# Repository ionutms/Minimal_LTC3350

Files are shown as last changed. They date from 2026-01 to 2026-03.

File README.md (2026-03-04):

# Minimal_LTC3350

## Overview

This repository contains a minimal KiCad design project for the Analog Devices LTC3350, a high-current supercapacitor backup controller and system monitor. The project includes schematic designs and PCB layout files for implementing this versatile backup power solution.

## Disclaimer

> [!NOTE]
> This project is provided "as is" and without any warranty, express or implied. For more details, please see the [LICENSE](LICENSE) file.

## About the LTC3350

The LTC3350 from Analog Devices is a high-current supercapacitor backup controller and system monitor designed for high-reliability backup power applications. It integrates a synchronous step-down/step-up controller that charges and monitors a series stack of 1–4 supercapacitors.

Key features include:

- **High-Efficiency Power Conversion:**
  - Synchronous step-down CC/CV charging for 1–4 series supercapacitors
  - Step-up mode in backup for greater utilization of stored energy
  - Supports 10A+ charge and backup currents
- **Advanced Monitoring:**
  - 14-bit ADC for monitoring system voltages and currents
  - Capacitance and ESR monitoring
  - I²C/SMBus interface for reading monitored parameters
- **Protection Features:**
  - Active overvoltage protection shunts
  - Internal active balancers (no external balance resistors needed)
  - Dual ideal diode PowerPath™ controller with N-channel MOSFETs
- **Programmable Current Limit:** Prioritizes system load over capacitor charge current
- **Wide Operating Range:**
  - Input Voltage (VIN): 4.5V to 35V
  - Capacitor Voltage (VCAP): Up to 5V per capacitor
- **Package:** Available in a 38-lead QFN package (5mm × 7mm × 0.75mm) with exposed pad
- **Automotive Qualified:** AEC-Q100 qualified for automotive applications

## Project Structure

```
minimal_ltc3350/
├── minimal_ltc3350.kicad_pro                     # Project configuration file
├── minimal_ltc3350.kicad_sch                     # Main schematic file
├── minimal_ltc3350.kicad_pcb                     # PCB layout file
├── fp-lib-table                                  # Footprint library table
├── sym-lib-table                                 # Symbol library table
├── docs/                                         # Documentation files
│   ├── bom/                                      # Bill of Materials
│   │   └── minimal_ltc3350_ibom.html             # Interactive BOM file
│   ├── pictures/                                 # Images and photos
│   │   ├── 1_minimal_ltc3350_side.png            # Side view of PCB
│   │   ├── 2_minimal_ltc3350_top.png             # Top view of PCB
│   │   └── 3_minimal_ltc3350_bottom.png          # Bottom view of PCB
│   └── schematics/                               # Schematic PDF exports
│       └── minimal_ltc3350_schematics.pdf        # Complete schematics PDF
└── KiCAD_Symbols_Generator/                      # Submodule for symbol generation from CSV data
```

## Project Features

This design provides a minimal implementation of the LTC3350 with:

- Proper power supply connections for 4.5V to 35V input range
- Supercapacitor stack configuration (1–4 series capacitors)
- Active balancing circuitry
- I²C/SMBus communication interface
- Current sensing and monitoring
- Standard footprint for the 38-lead QFN package

## Getting Started

### Prerequisites

- [KiCad EDA](https://www.kicad.org/) version 9.0 or later installed on your system
- Git (for cloning the repository and submodule management)

### Opening the Project

1. **Clone the repository** (including submodules):
   ```bash
   git clone --recursive https://github.com/ionutms/Minimal_LTC3350.git
   ```

   If you've already cloned the repository without submodules, initialize them with:
   ```bash
   git submodule init
   git submodule update
   ```

2. **Open the project in KiCad**:
   - Launch KiCad
   - Click "Open Existing Project"
   - Navigate to the cloned repository folder
   - Select the `minimal_ltc3350.kicad_pro` file

3. **Explore the design**:
   - Open the schematic editor to view the circuit design
   - Open the PCB editor to view the board layout
   - Review the symbol and footprint libraries used in the design

### Project Files

- **Main schematic**: `minimal_ltc3350.kicad_sch` - Contains the primary circuit design with the LTC3350 and support components
- **PCB layout**: `minimal_ltc3350.kicad_pcb` - Physical board design file with proper component placement
- **Project configuration**: `minimal_ltc3350.kicad_pro` - KiCad project settings

## Dependencies

This project has the following dependencies:

### 1. KiCAD Symbols Generator

This repository uses [KiCAD_Symbols_Generator](https://github.com/ionutms/KiCAD_Symbols_Generator) as a submodule for custom symbol generation.

To initialize the submodule after cloning this repository:

```bash
git submodule update --init --recursive
```

### 2. 3D Models

This project requires the [3D_Models_Vault](https://github.com/ionutms/3D_Models_Vault) repository for 3D models.

#### Setup for KiCAD 9:

1. Clone the 3D models repository:
   ```bash
   git clone https://github.com/ionutms/3D_Models_Vault.git
   ```

2. In KiCAD 9, add an environment variable:
   - Variable name: `KICAD9_3D_MODELS_VAULT`
   - Variable value: Full path to where you cloned the 3D_Models_Vault repository

## Usage

After setting up the dependencies, open the project in KiCad 9 to access all features including the 3D models.

## Symbol Generator Submodule

This project includes the KiCAD_Symbols_Generator as a submodule, which provides tools for generating KiCad symbols from CSV data files. For more information on using this tool, see the [KiCAD_Symbols_Generator documentation](minimal_ltc3350/KiCAD_Symbols_Generator/README.md).

## Documentation

The `docs` folder contains:
- Schematic PDF exports
- Images and photos of the design

## Visuals

The following images showcase the PCB design from different perspectives:

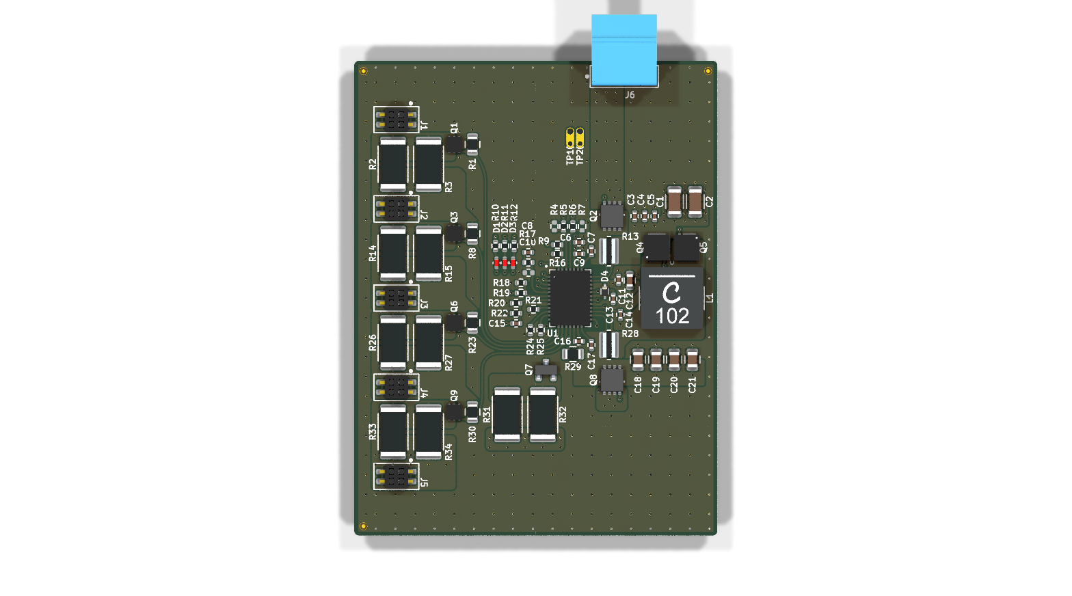
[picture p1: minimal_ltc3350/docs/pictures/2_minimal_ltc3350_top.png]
Top View

*Top View of the PCB*

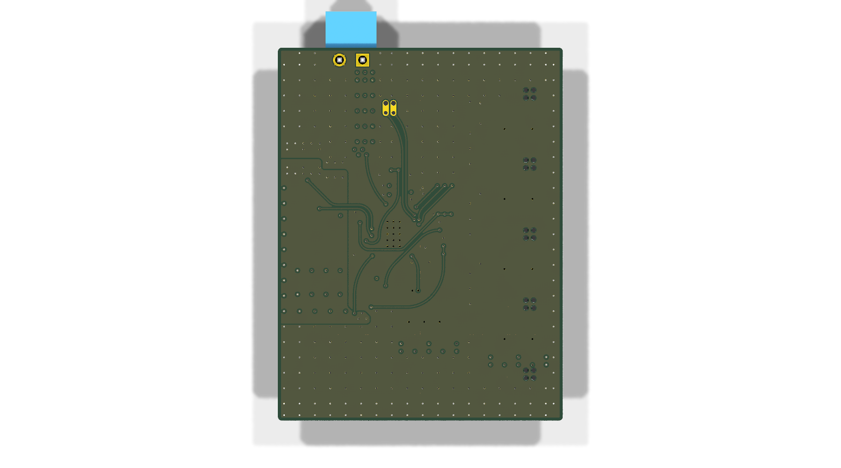
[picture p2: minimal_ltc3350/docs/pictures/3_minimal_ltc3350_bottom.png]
Bottom View

*Bottom View of the PCB*

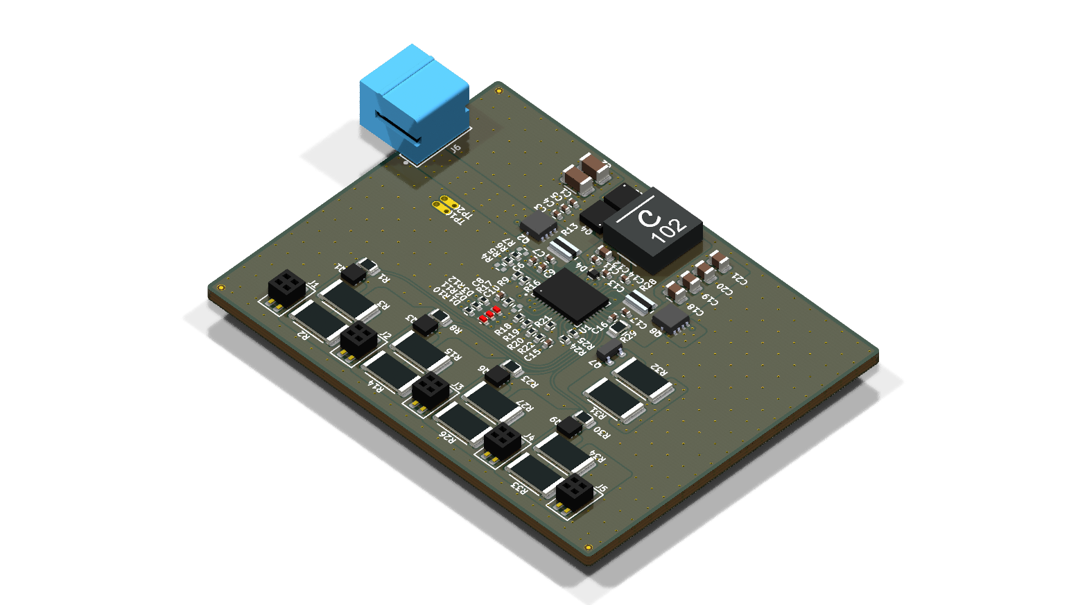
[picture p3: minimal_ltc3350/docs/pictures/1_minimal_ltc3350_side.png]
Side View

*Side View of the PCB*

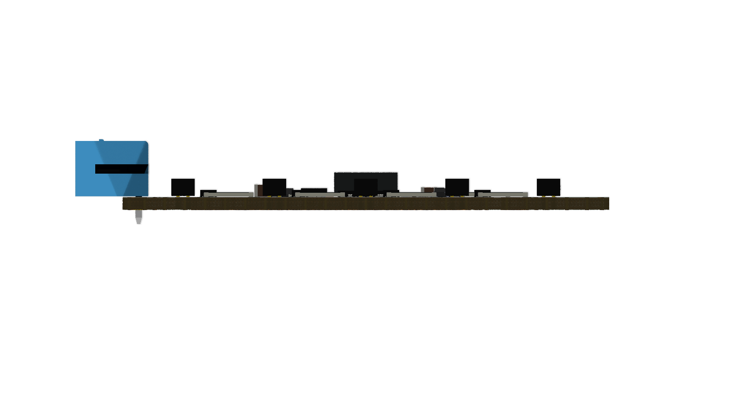
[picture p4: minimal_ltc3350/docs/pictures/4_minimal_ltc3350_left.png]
Left View

*Left View of the PCB*

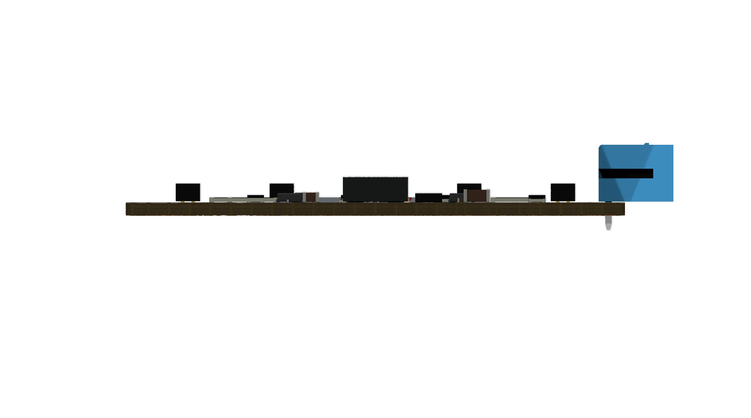
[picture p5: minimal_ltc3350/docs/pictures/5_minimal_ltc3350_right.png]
Right View

*Right View of the PCB*

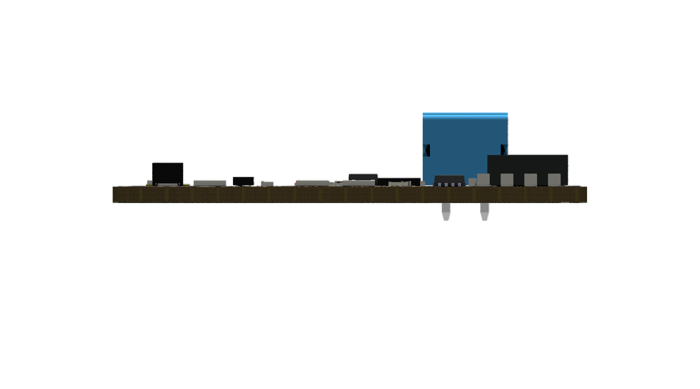
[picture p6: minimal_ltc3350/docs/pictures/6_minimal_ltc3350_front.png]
Front View

*Front View of the PCB*

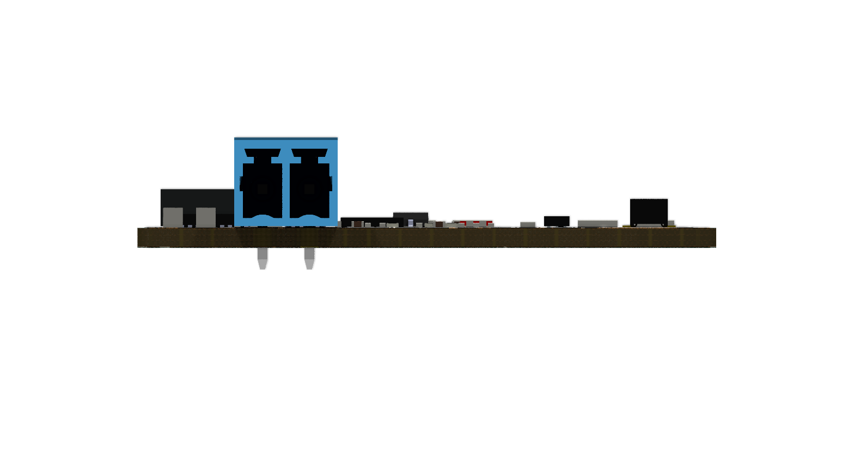
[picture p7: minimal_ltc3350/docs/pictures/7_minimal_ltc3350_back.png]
Back View

*Back View of the PCB*

## License

This project is licensed under the MIT License - see the [LICENSE](LICENSE) file for details.

## References

- [LTC3350 Datasheet](https://www.analog.com/media/en/technical-documentation/data-sheets/ltc3350.pdf)
- [LTC3350 Product Page](https://www.analog.com/en/products/ltc3350.html)
- [KiCad EDA](https://www.kicad.org/)

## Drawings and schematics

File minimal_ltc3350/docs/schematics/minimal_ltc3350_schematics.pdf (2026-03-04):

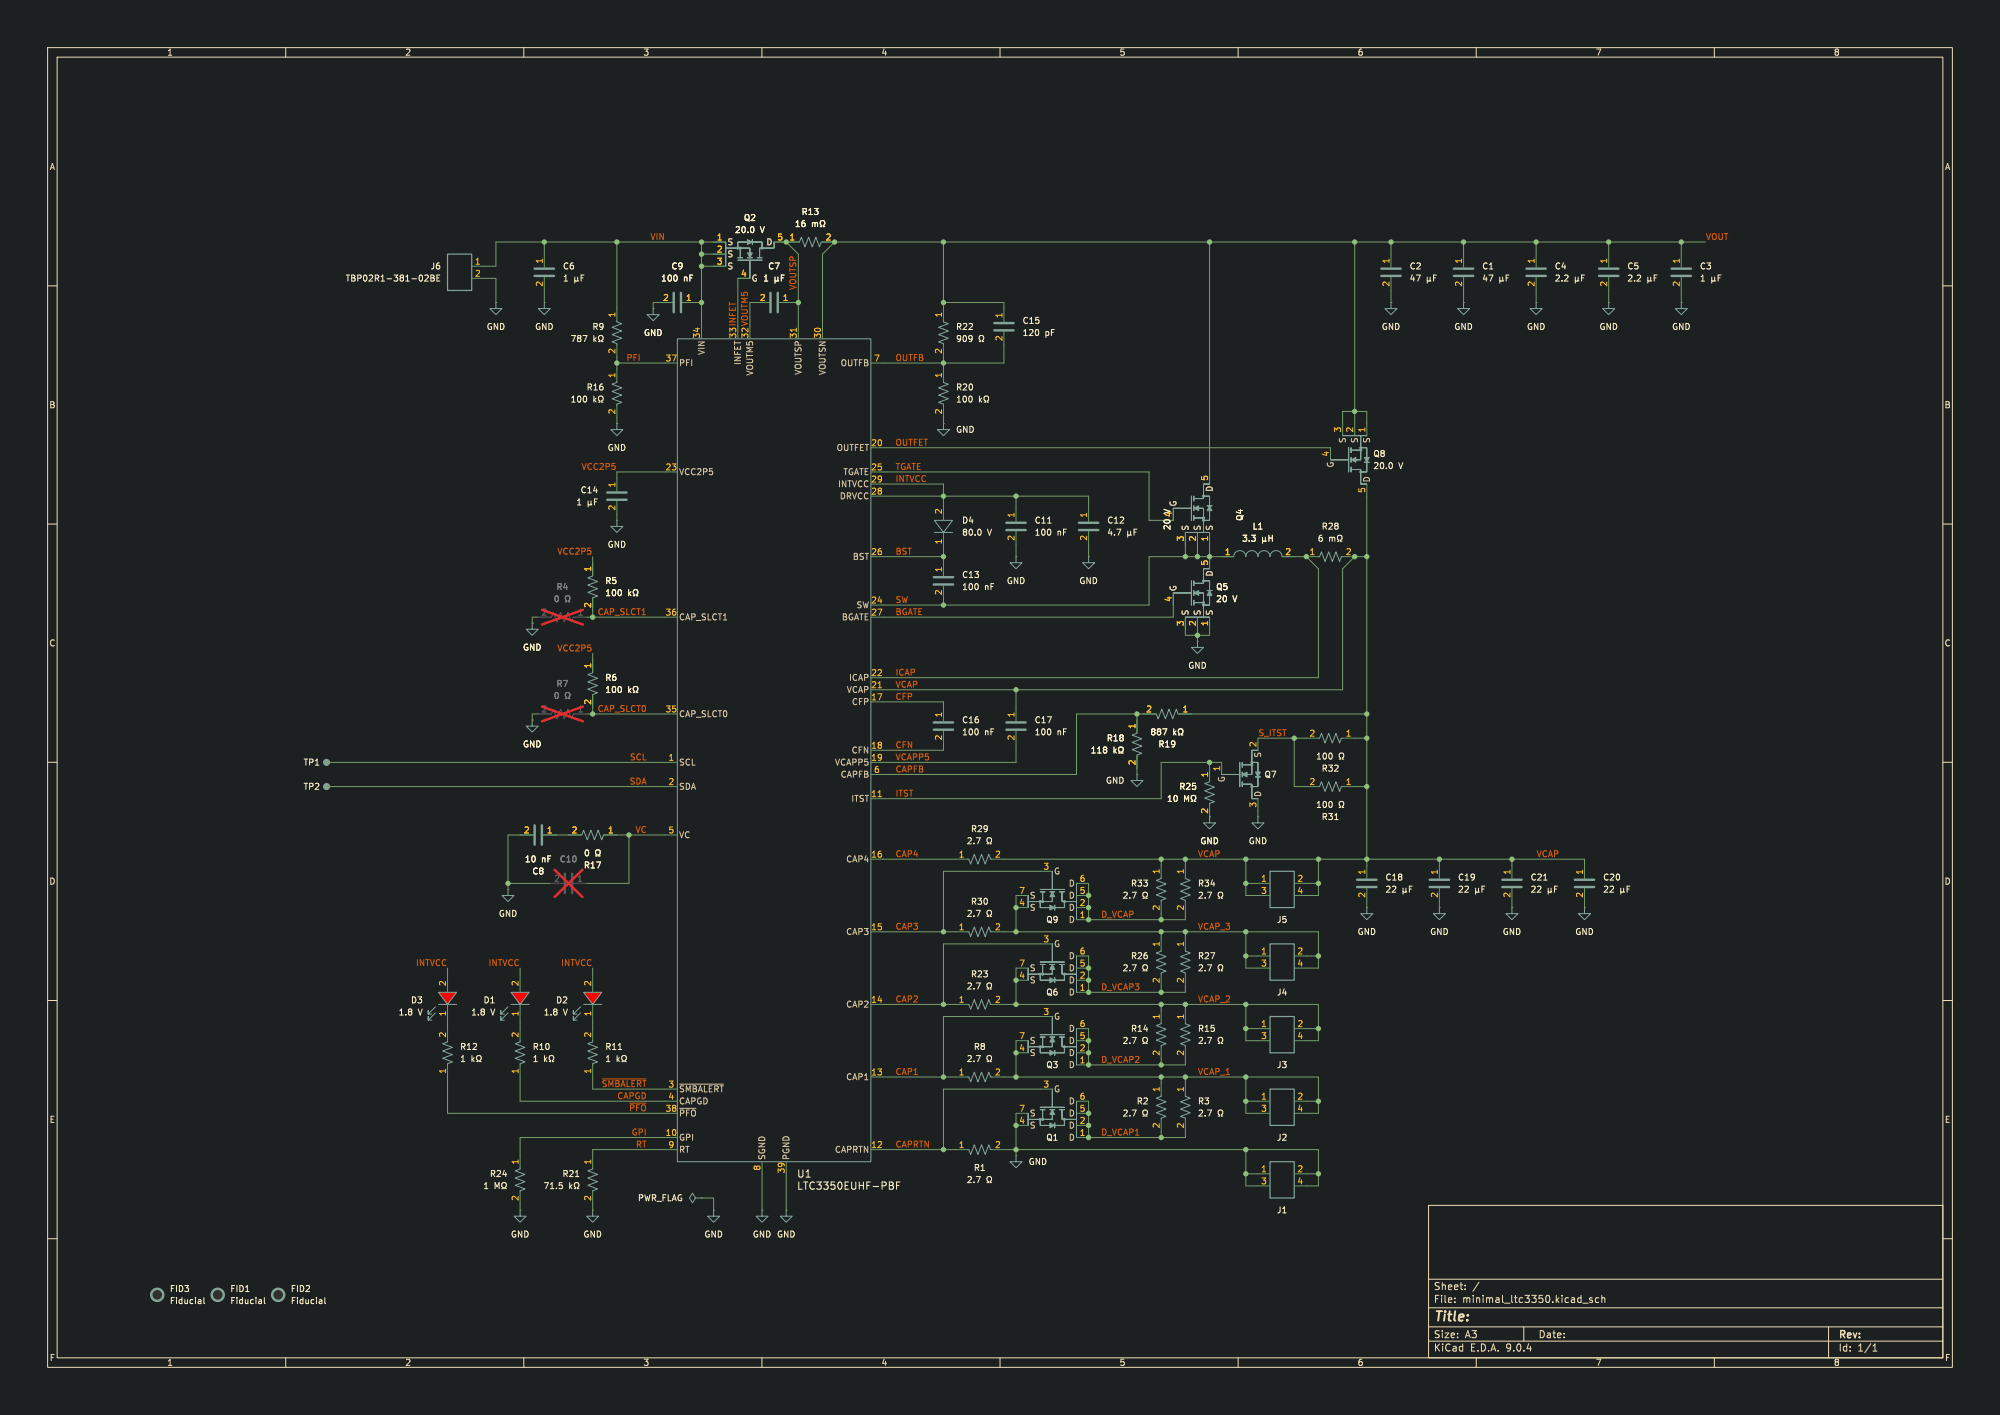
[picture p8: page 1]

8 PGND 39 VOUTSP 31 VOUTSN 30 OUTFB 7 OUTFET20 TGATE25

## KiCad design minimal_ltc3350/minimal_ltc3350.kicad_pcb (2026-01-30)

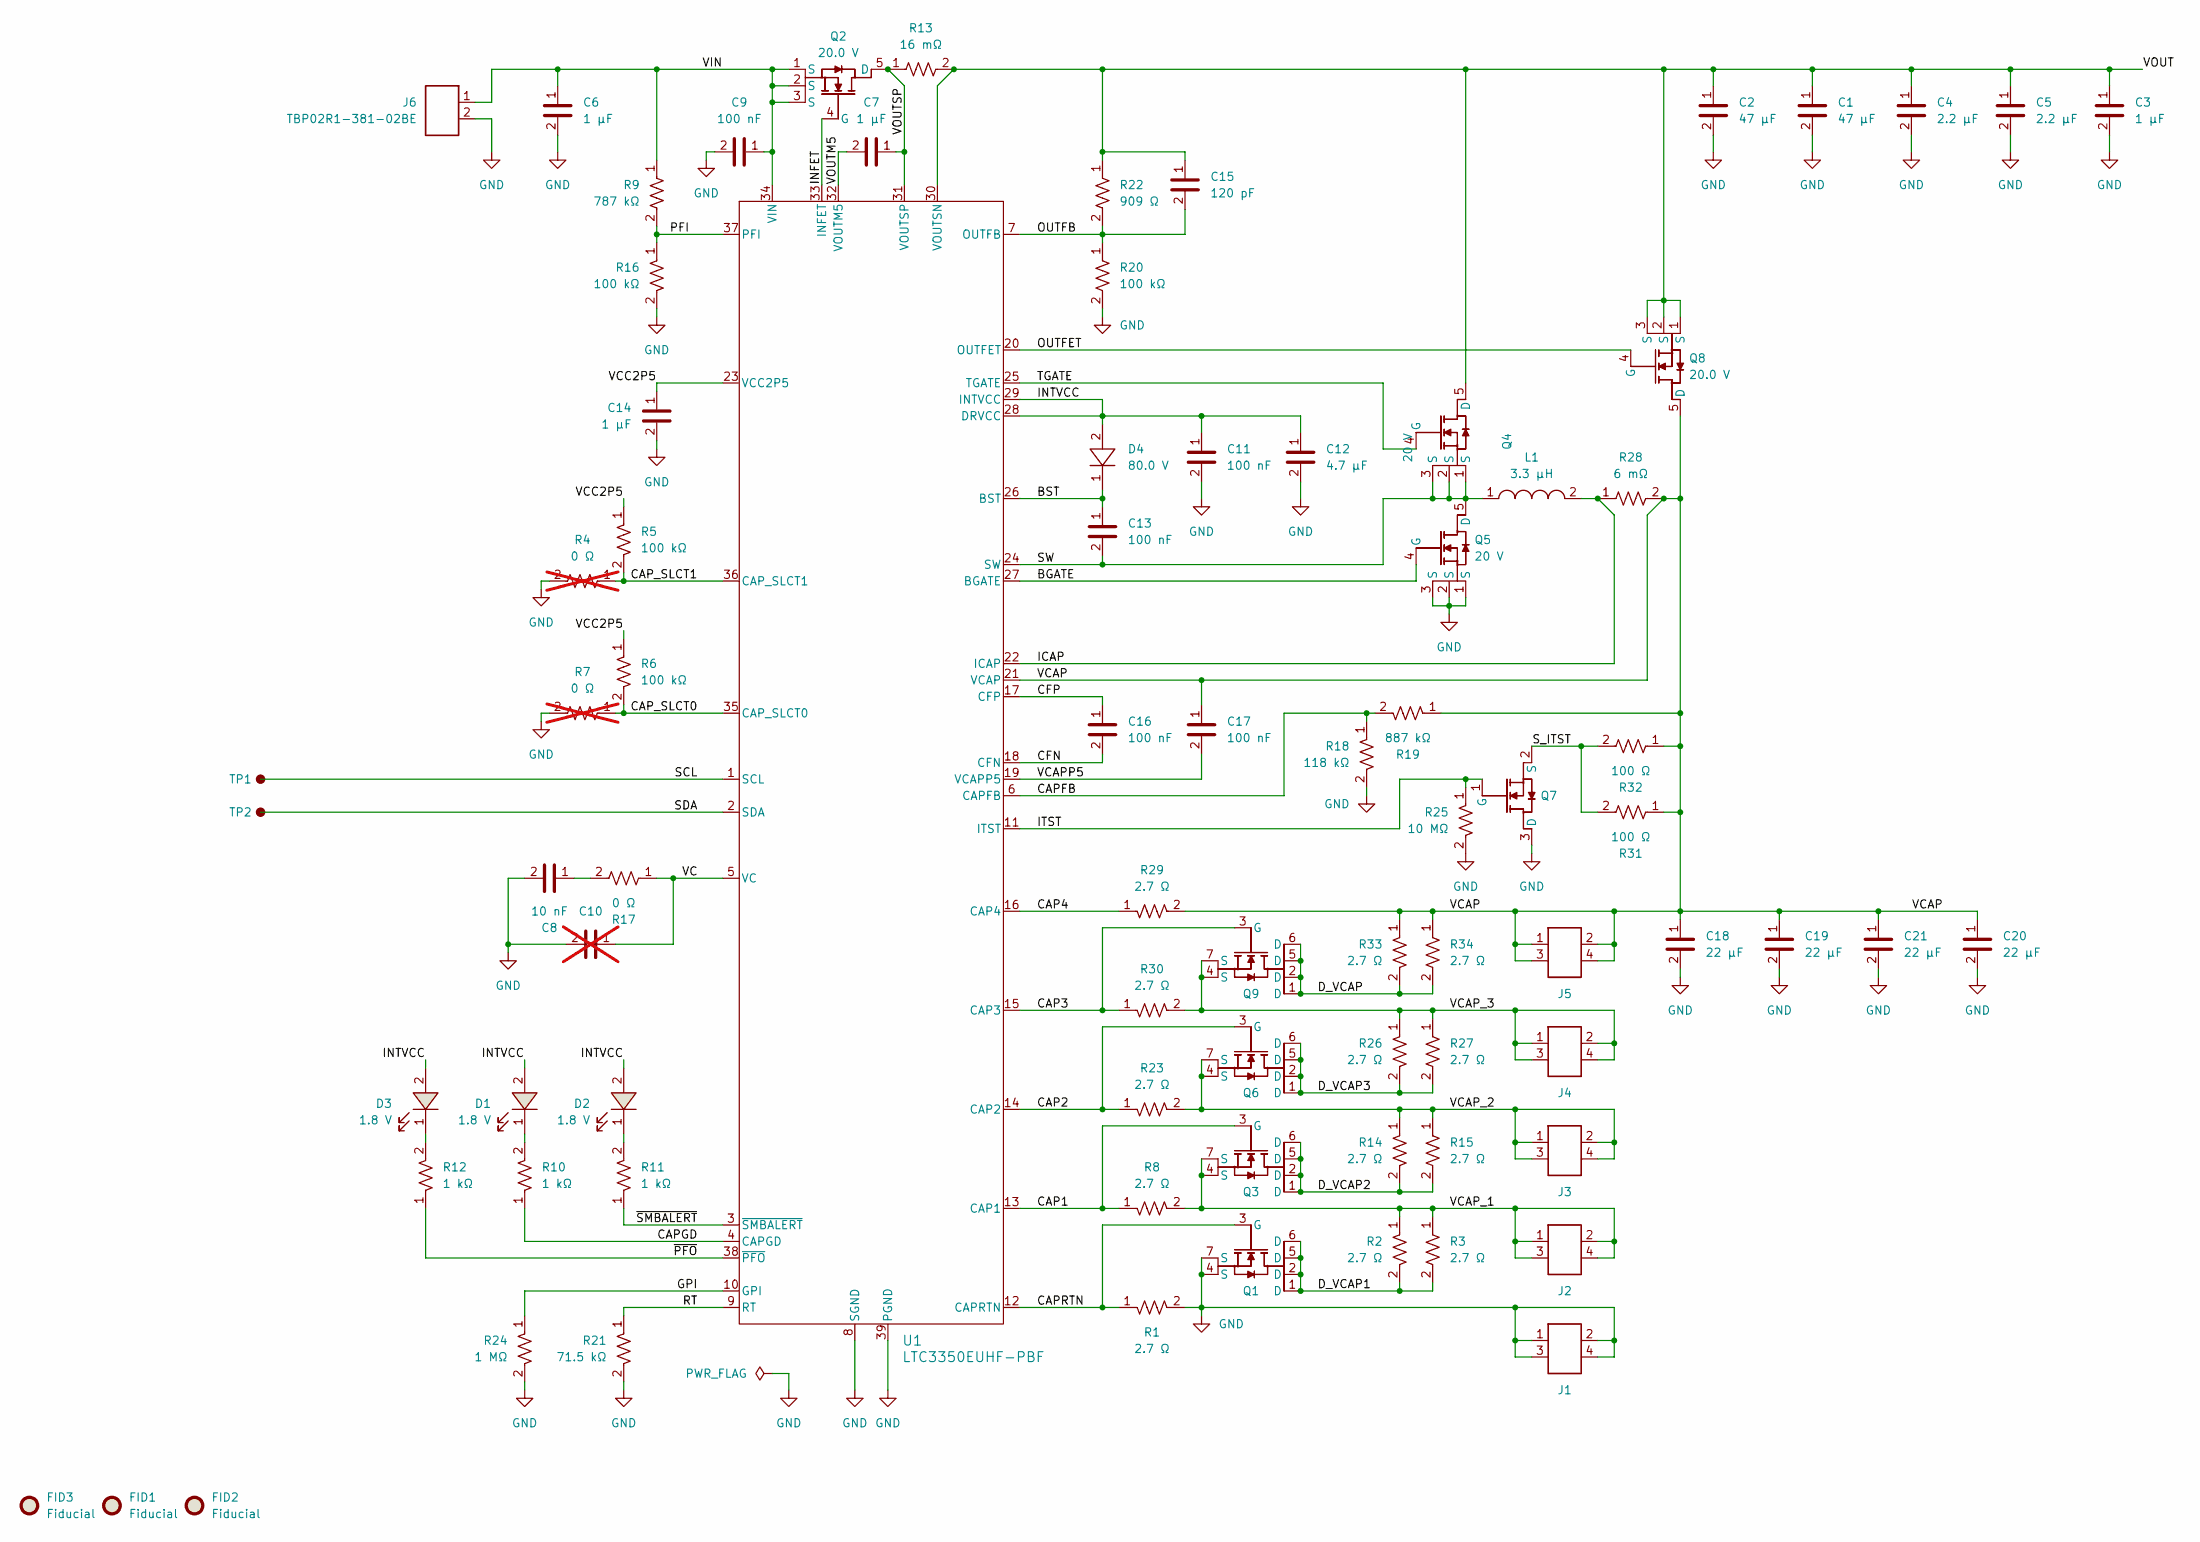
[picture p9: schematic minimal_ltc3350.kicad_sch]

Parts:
C1, C2: 47 µF; C_1206_3216Metric; Tolerance 20%; Voltage Rating 25V; MPN C3216X5R1E476M160AC
C3, C6, C7: 1 µF; C_0402_1005Metric; Tolerance 10%; Voltage Rating 25V; MPN C1005X5R1E105K050BC
C4, C5: 2.2 µF; C_0402_1005Metric; Tolerance 10%; Voltage Rating 25V; MPN C1005X5R1E225K050BC
C8: 10 nF; C_0402_1005Metric; Tolerance 10%; Voltage Rating 50V; MPN GCM155R71H103KA55D
C9, C11, C13, C16, C17: 100 nF; C_0402_1005Metric; Tolerance 10%; Voltage Rating 50V; MPN GCM155R71H104KE02D
C10: 10 nF; C_0402_1005Metric; Tolerance 10%; Voltage Rating 50V; MPN GCM155R71H103KA55D; not fitted
C12: 4.7 µF; C_0603_1608Metric; Tolerance 10%; Voltage Rating 10V; MPN GRM188C71A475KE11D
C14: 1 µF; C_0402_1005Metric; Tolerance 10%; Voltage Rating 16V; MPN C1005X6S1C105K050BC
C15: 120 pF; C_0402_1005Metric; Tolerance 1%; Voltage Rating 50V; MPN GCM1555C1H121FA16D
C18, C19, C20, C21: 22 µF; C_0805_2012Metric; Tolerance 20%; Voltage Rating 16V; MPN C2012X5R1C226M125AC
D1, D2, D3: 1.8 V; LED_RED_0402_1005Metric; MPN APHHS1005LSECK/J3-PF
D4: 80.0 V; SOD_523; MPN 1N4448HWT-7
FID1, FID2, FID3: Fiducial; Fiducial_0.5mm_Mask1mm
J1, J2, J3, J4, J5: CLP-102-02-G-D-BE; Current Rating (A) 5.2; Voltage Rating (V) 300; MPN CLP-102-02-G-D-BE
J6: TBP02R1-381-02BE; Current Rating (A) 8.0; Voltage Rating (V) 300; MPN TBP02R1-381-02BE
L1: 3.3 µH; XAL7030; Tolerance ±20%; MPN XAL7030-332ME
Q1, Q3, Q6, Q9: 8 V; PowerPAK SC-70; MPN SIA436DJ-T1-GE3
Q2, Q8: 20.0 V; PowerPAK 1212-8; MPN SIS438DN-T1-GE3
Q4, Q5: 20 V; TSDSON-8FL; MPN BSZ060NE2LS
Q7: 20.0 V; SOT23; MPN SI2374DS-T1-BE3
R1, R8, R23, R29, R30: 2.7 Ω; R_0805_2012Metric; Tolerance 1%; Voltage Rating 150V; MPN ERJ-6DQF2R7V
R2, R3, R14, R15, R26, R27, R33, R34: 2.7 Ω; R_2512_6332Metric; Tolerance 1%; Voltage Rating 200V; MPN RC2512FK-7W2R7L
R4, R7: 0 Ω; R_0402_1005Metric; Tolerance 5%; Voltage Rating 50V; MPN ERJ-2GE0R00X; not fitted
R5, R6, R16, R20: 100 kΩ; R_0402_1005Metric; Tolerance 1%; Voltage Rating 50V; MPN ERJ-2RKF1003X
R9: 787 kΩ; R_0402_1005Metric; Tolerance 1%; Voltage Rating 50V; MPN ERJ-2RKF7873X
R10, R11, R12: 1 kΩ; R_0402_1005Metric; Tolerance 1%; Voltage Rating 50V; MPN ERJ-2RKF1001X
R13: 16 mΩ; R_0612_1632Metric; Tolerance 1%; MPN ERJ-B2CFR016V
R17: 0 Ω; R_0402_1005Metric; Tolerance 5%; Voltage Rating 50V; MPN ERJ-2GE0R00X
R18: 118 kΩ; R_0402_1005Metric; Tolerance 1%; Voltage Rating 50V; MPN ERJ-2RKF1183X
R19: 887 kΩ; R_0402_1005Metric; Tolerance 1%; Voltage Rating 50V; MPN ERJ-2RKF8873X
R21: 71.5 kΩ; R_0402_1005Metric; Tolerance 1%; Voltage Rating 50V; MPN ERJ-2RKF7152X
R22: 909 Ω; R_0402_1005Metric; Tolerance 1%; Voltage Rating 50V; MPN ERJ-2RKF9090X
R24: 1 MΩ; R_0402_1005Metric; Tolerance 1%; Voltage Rating 50V; MPN ERJ-2RKF1004X
R25: 10 MΩ; R_0402_1005Metric; Tolerance 1%; Voltage Rating 50V; MPN RC0402FR-0710ML
R28: 6 mΩ; R_0612_1632Metric; Tolerance 1%; MPN WFCP06126L000FE66
R31, R32: 100 Ω; R_2512_6332Metric; Tolerance 1%; Voltage Rating 200V; MPN SR2512FK-7W100RL
TP1, TP2: TestPoint; TestPoint_THTPad_Castelated
U1: LTC3350EUHF-PBF; QFN-38_UHF_LIT; MPN LTC3350EUHF#PBF

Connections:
/BGATE: Q5.4 (G), U1.27 (BGATE)
/BST: C13.1, D4.1, U1.26 (BST)
/CAP1: Q3.3 (G), R8.1, U1.13 (CAP1)
/CAP2: Q6.3 (G), R23.1, U1.14 (CAP2)
/CAP3: Q9.3 (G), R30.1, U1.15 (CAP3)
/CAP4: R29.1, U1.16 (CAP4)
/CAPFB: R18.1, R19.2, U1.6 (CAPFB)
/CAPGD: R10.1, U1.4 (CAPGD)
/CAPRTN: Q1.3 (G), R1.1, U1.12 (CAPRTN)
/CAP_SLCT0: R6.2, R7.1, U1.35 (CAP_SLCT0)
/CAP_SLCT1: R4.1, R5.2, U1.36 (CAP_SLCT1)
/CFN: C16.2, U1.18 (CFN)
/CFP: C16.1, U1.17 (CFP)
/D_VCAP: Q9.1 (D), Q9.2 (D), Q9.5 (D), Q9.6 (D), R33.2, R34.2
/D_VCAP1: Q1.1 (D), Q1.2 (D), Q1.5 (D), Q1.6 (D), R2.2, R3.2
/D_VCAP2: Q3.1 (D), Q3.2 (D), Q3.5 (D), Q3.6 (D), R14.2, R15.2
/D_VCAP3: Q6.1 (D), Q6.2 (D), Q6.5 (D), Q6.6 (D), R26.2, R27.2
/GPI: R24.1, U1.10 (GPI)
/ICAP: L1.2, R28.1, U1.22 (ICAP)
/INFET: Q2.4 (G), U1.33 (INFET)
/INTVCC: C11.1, C12.1, D1.2, D2.2, D3.2, D4.2, U1.28 (DRVCC), U1.29 (INTVCC)
/ITST: Q7.1 (G), R25.1, U1.11 (ITST)
/OUTFB: C15.2, R20.1, R22.2, U1.7 (OUTFB)
/OUTFET: Q8.4 (G), U1.20 (OUTFET)
/PFI: R9.2, R16.1, U1.37 (PFI)
/RT: R21.1, U1.9 (RT)
/SCL: TP1.1, U1.1 (SCL)
/SDA: TP2.1, U1.2 (SDA)
/SW: C13.2, L1.1, Q4.1 (S), Q4.2 (S), Q4.3 (S), Q5.5 (D), U1.24 (SW)
/S_ITST: Q7.2 (S), R31.2, R32.2
/TGATE: Q4.4 (G), U1.25 (TGATE)
/VC: C10.1, R17.1, U1.5 (VC)
/VCAP: C17.1, C18.1, C19.1, C20.1, C21.1, J5.1, J5.2, J5.3, J5.4, Q8.5 (D), R19.1, R28.2, R29.2, R31.1, R32.1, R33.1, R34.1, U1.21 (VCAP)
/VCAPP5: C17.2, U1.19 (VCAPP5)
/VCAP_1: J2.1, J2.2, J2.3, J2.4, Q3.4 (S), Q3.7 (S), R2.1, R3.1, R8.2
/VCAP_2: J3.1, J3.2, J3.3, J3.4, Q6.4 (S), Q6.7 (S), R14.1, R15.1, R23.2
/VCAP_3: J4.1, J4.2, J4.3, J4.4, Q9.4 (S), Q9.7 (S), R26.1, R27.1, R30.2
/VCC2P5: C14.1, R5.1, R6.1, U1.23 (VCC2P5)
/VIN: C6.1, C9.1, J6.1, Q2.1 (S), Q2.2 (S), Q2.3 (S), R9.1, U1.34 (VIN)
/VOUT: C1.1, C2.1, C3.1, C4.1, C5.1, C15.1, Q4.5 (D), Q8.1 (S), Q8.2 (S), Q8.3 (S), R13.2, R22.1, U1.30 (VOUTSN)
/VOUTM5: C7.2, U1.32 (VOUTM5)
/VOUTSP: C7.1, Q2.5 (D), R13.1, U1.31 (VOUTSP)
/~PFO: R12.1, U1.38 (~PFO)
/~SMBALERT: R11.1, U1.3 (~SMBALERT)
GND: C1.2, C2.2, C3.2, C4.2, C5.2, C6.2, C8.2, C9.2, C10.2, C11.2, C12.2, C14.2, C18.2, C19.2, C20.2, C21.2, J1.1, J1.2, J1.3, J1.4, J6.2, Q1.4 (S), Q1.7 (S), Q5.1 (S), Q5.2 (S), Q5.3 (S), Q7.3 (D), R1.2, R4.2, R7.2, R16.2, R18.2, R20.2, R21.2, R24.2, R25.2, U1.8 (SGND), U1.39 (PGND)
unnamed: C8.1, R17.2
unnamed: D1.1, R10.2
unnamed: D2.1, R11.2
unnamed: D3.1, R12.2

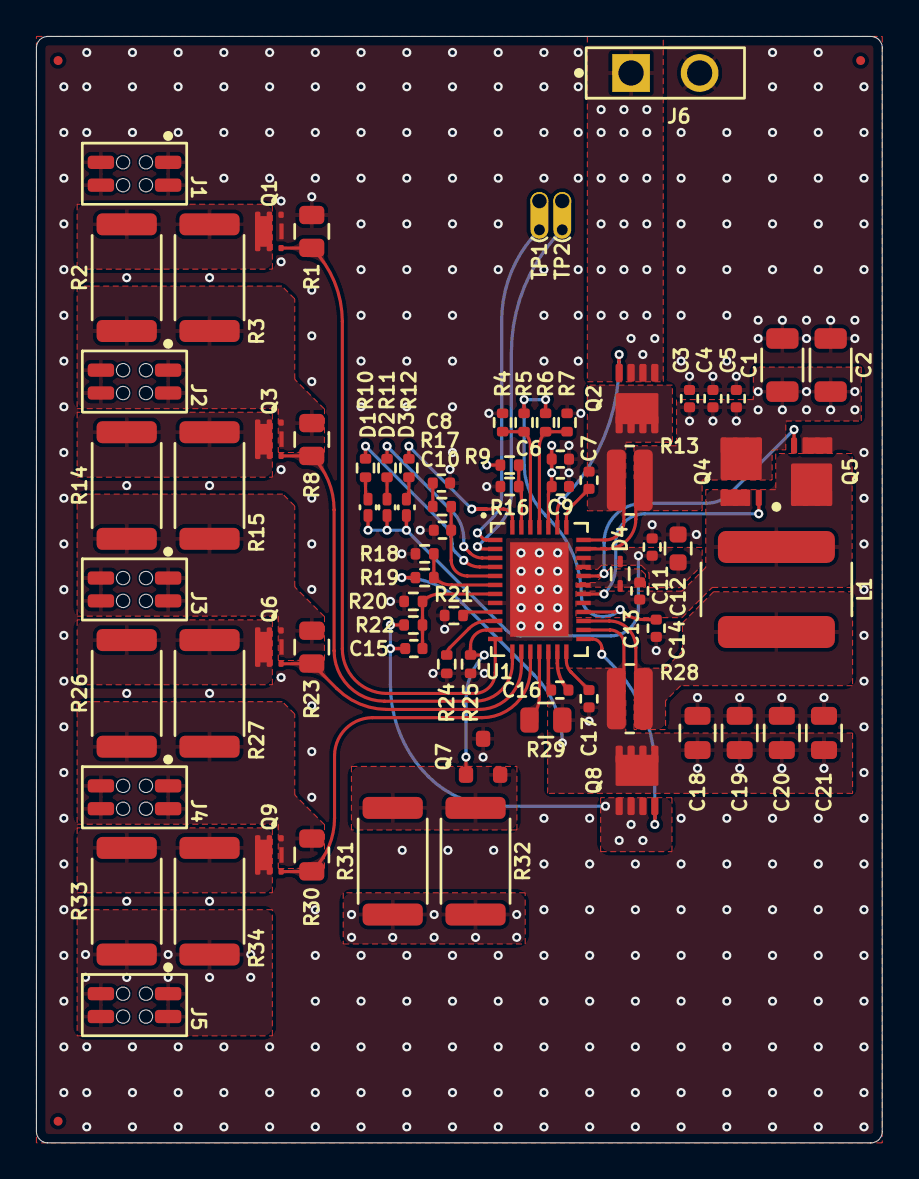
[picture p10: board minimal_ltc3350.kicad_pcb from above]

Board: 4 copper layers, 47.0 x 61.5 mm, 81 parts (0 on the bottom side), 49 nets.

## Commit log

2025-12-01 Add KiCad project files for Minimal_LTC3350
    [minimal_ltc3350.kicad_pcb, minimal_ltc3350.kicad_sch]
2025-12-01 Add git submodules configuration and KiCAD Symbols Generator
2025-12-01 Add KiCad library table files (fp-lib-table and sym-lib-table)
2025-12-01 Update KiCad project files (PCB layout and project settings)
    [minimal_ltc3350.kicad_pcb]
2025-12-01 chore: update workflows and kicad config from central repository
2025-12-01 Update KiCad documentation for minimal_ltc3350 (schematics and PCB renders)
2025-12-01 Update KiCad project files (PCB layout, project settings, and schematic)
    [minimal_ltc3350.kicad_pcb, minimal_ltc3350.kicad_sch]
2025-12-01 Update KiCad project files and submodule reference
    [minimal_ltc3350.kicad_pcb, minimal_ltc3350.kicad_sch]
2025-12-01 Add VOUT sensing resistor and update symbol libraries
    [minimal_ltc3350.kicad_pcb, minimal_ltc3350.kicad_sch]
2025-12-02 Update schematic and PCB with VOUT sensing resistor and component changes
    [minimal_ltc3350.kicad_pcb, minimal_ltc3350.kicad_sch]
2025-12-03 Update KiCad project: Component changes and layout improvements
    [minimal_ltc3350.kicad_pcb, minimal_ltc3350.kicad_sch]
2025-12-04 Update KiCad project: Component changes, net updates, and symbol library additions
    [minimal_ltc3350.kicad_pcb, minimal_ltc3350.kicad_sch]
2025-12-05 Update KiCad project files: PCB layout, schematic, project settings, and symbols generator
    [minimal_ltc3350.kicad_pcb, minimal_ltc3350.kicad_sch]
2025-12-06 Update KiCAD PCB and schematic files
    [minimal_ltc3350.kicad_pcb, minimal_ltc3350.kicad_sch]
2025-12-06 Add C19 capacitor and update component positions in KiCad project
    [minimal_ltc3350.kicad_pcb, minimal_ltc3350.kicad_sch]
2025-12-07 Update component positions and adjust properties in KiCad PCB design
    [minimal_ltc3350.kicad_pcb]
2025-12-07 Update KiCAD PCB file
    [minimal_ltc3350.kicad_pcb]
2025-12-07 Update KiCAD project files and symbols generator
    [minimal_ltc3350.kicad_pcb, minimal_ltc3350.kicad_sch]
2025-12-08 Update KiCad project: Add LED components and adjust resistor positions
    [minimal_ltc3350.kicad_pcb, minimal_ltc3350.kicad_sch]
2025-12-09 Update KiCad project: Update PCB layout and schematic
    [minimal_ltc3350.kicad_pcb, minimal_ltc3350.kicad_sch]
2025-12-11 Update KiCAD files and symbol table
    [minimal_ltc3350.kicad_pcb, minimal_ltc3350.kicad_sch]
2025-12-12 Update KiCAD symbols generator and schematic file
    [minimal_ltc3350.kicad_sch]
2025-12-13 Update KiCad project files: add new transistor components and connect nets
    [minimal_ltc3350.kicad_pcb, minimal_ltc3350.kicad_sch]
2025-12-14 Update KiCad project: PCB layout improvements and schematic changes
    [minimal_ltc3350.kicad_pcb, minimal_ltc3350.kicad_sch]
2025-12-21 Update KiCAD project files and symbol table
    [minimal_ltc3350.kicad_pcb, minimal_ltc3350.kicad_sch]
2025-12-21 Update capacitor symbols orientation and positioning in schematic
    [minimal_ltc3350.kicad_sch]
2025-12-22 Update KiCAD files: symbols generator, schematic, and PCB layout
    [minimal_ltc3350.kicad_pcb, minimal_ltc3350.kicad_sch]
2025-12-25 Update KiCad project files
    [minimal_ltc3350.kicad_pcb, minimal_ltc3350.kicad_sch]
2025-12-25 docs: update KiCad files
    [minimal_ltc3350.kicad_pcb, minimal_ltc3350.kicad_sch]
2025-12-29 feat: Update KiCad project and symbols
    [minimal_ltc3350.kicad_pcb, minimal_ltc3350.kicad_sch]
2025-12-30 Update KiCAD project files: Remove component properties and adjust zone connections
    [minimal_ltc3350.kicad_pcb]
2025-12-31 Update KiCad schematic and PCB files
    [minimal_ltc3350.kicad_pcb, minimal_ltc3350.kicad_sch]
2026-01-01 Update KiCad project files: PCB layout, project settings, and schematic
    [minimal_ltc3350.kicad_pcb, minimal_ltc3350.kicad_sch]
2026-01-02 Update KiCAD Symbols Generator and PCB layout changes
    [minimal_ltc3350.kicad_pcb]
2026-01-02 Update KiCAD project files: PCB and schematic
    [minimal_ltc3350.kicad_pcb, minimal_ltc3350.kicad_sch]
2026-01-03 Update KiCad project: Add supercap bank component and update net connections
    [minimal_ltc3350.kicad_pcb, minimal_ltc3350.kicad_sch]
2026-01-03 Update KiCAD config: adjust zoom factor and pan position
2026-01-11 wip: latest changes
    [minimal_ltc3350.kicad_pcb, minimal_ltc3350.kicad_sch]
2026-01-18 Update kicad-config.yml and remove unused test picture
2026-01-18 Update KiCAD configuration settings
2026-01-30 Update KiCad files
    [minimal_ltc3350.kicad_pcb, minimal_ltc3350.kicad_sch]
